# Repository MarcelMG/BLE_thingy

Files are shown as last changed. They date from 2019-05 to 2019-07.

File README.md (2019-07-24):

# BLEthingy
BLEthingy is a small battery-powered device with Bluetooth-Low-Energy connectivity.

The main microcontroller used is an AVR ATtiny3216 from the new tiny-1 series.

BLE connectivity is provided by a RN4871-I RF module.

There is an ADXL345 3-axis accelerometer onboard for motion detection. It sits on a GY-291 breakout-board, which is very cheap and avoids hand-soldering the tiny package of the ADXL345 which is virtually impossible without hot air / reflow oven. The GY-291 has to be slightly modified, see [here](https://github.com/MarcelMG/BLE_thingy/blob/master/hardware/GY-291_mod.md) for further instructions.

A pushbutton and a user LED are also onboard.

On the back of the PCB, a holder for a CR2032 coin cell is mounted.

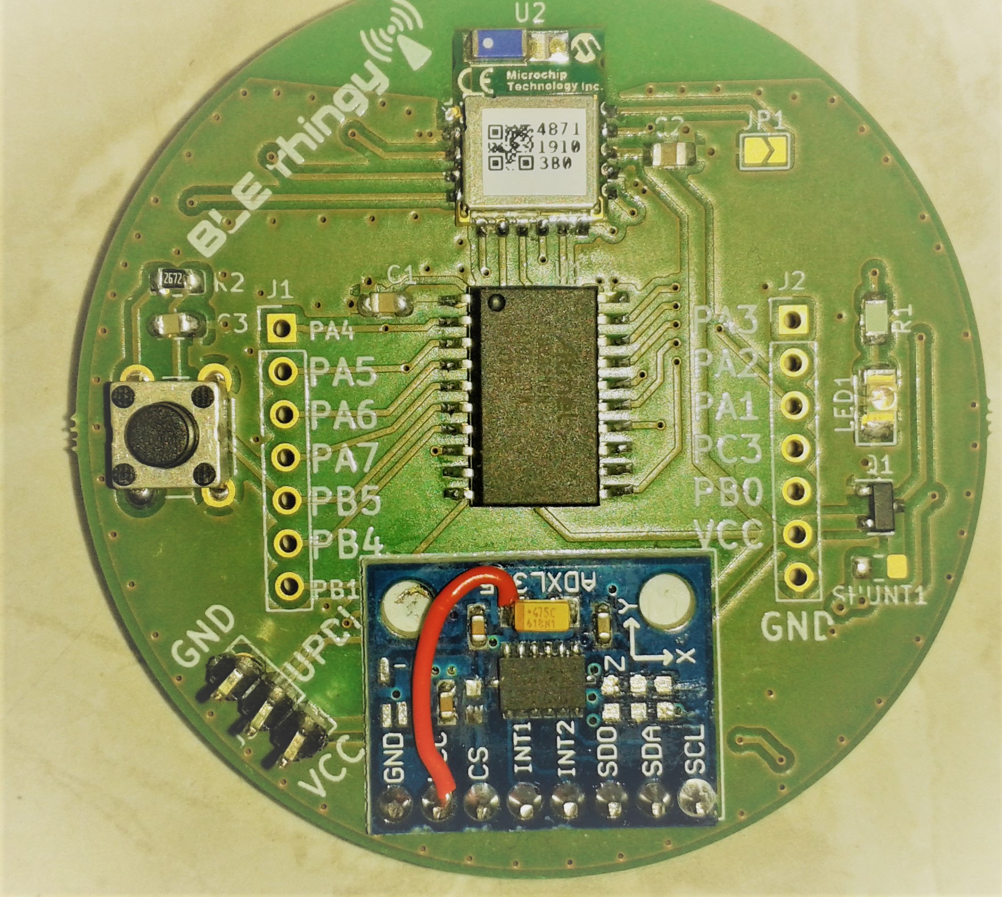
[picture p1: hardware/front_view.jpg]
front_view

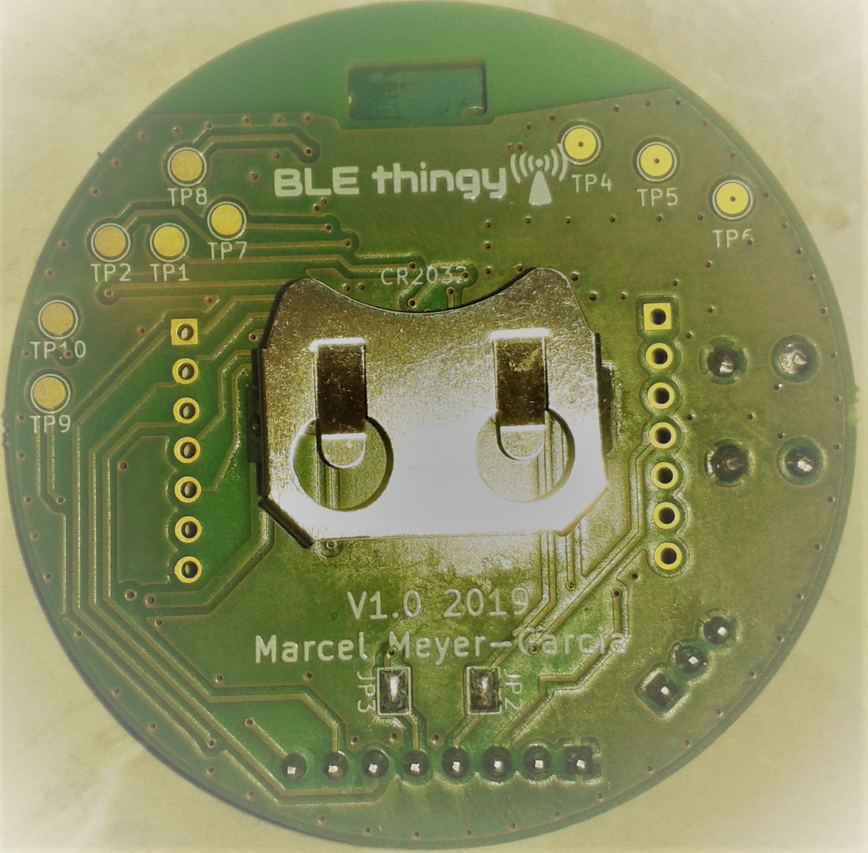
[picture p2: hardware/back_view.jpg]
back_view


An enclosure has been designed which can be 3D-printed.

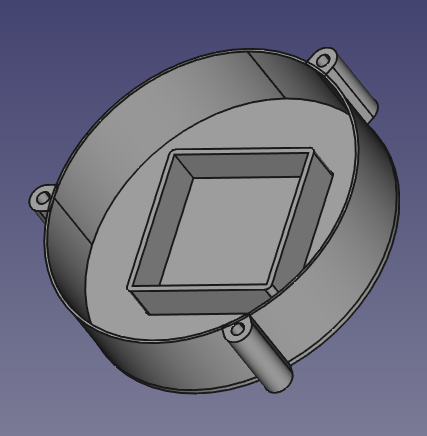
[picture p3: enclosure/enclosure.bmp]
enclosure

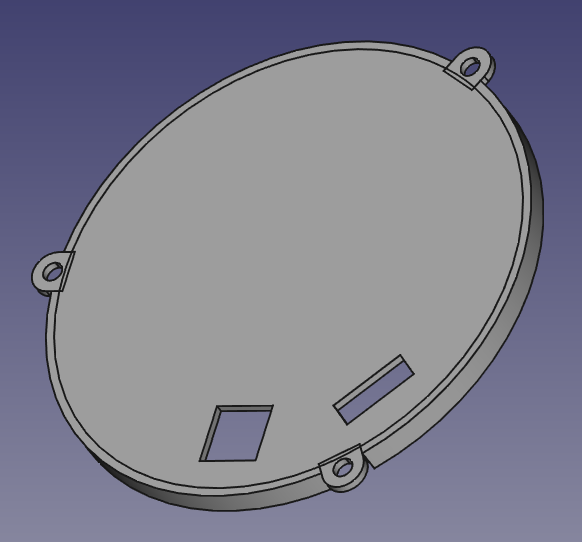
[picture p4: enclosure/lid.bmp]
lid

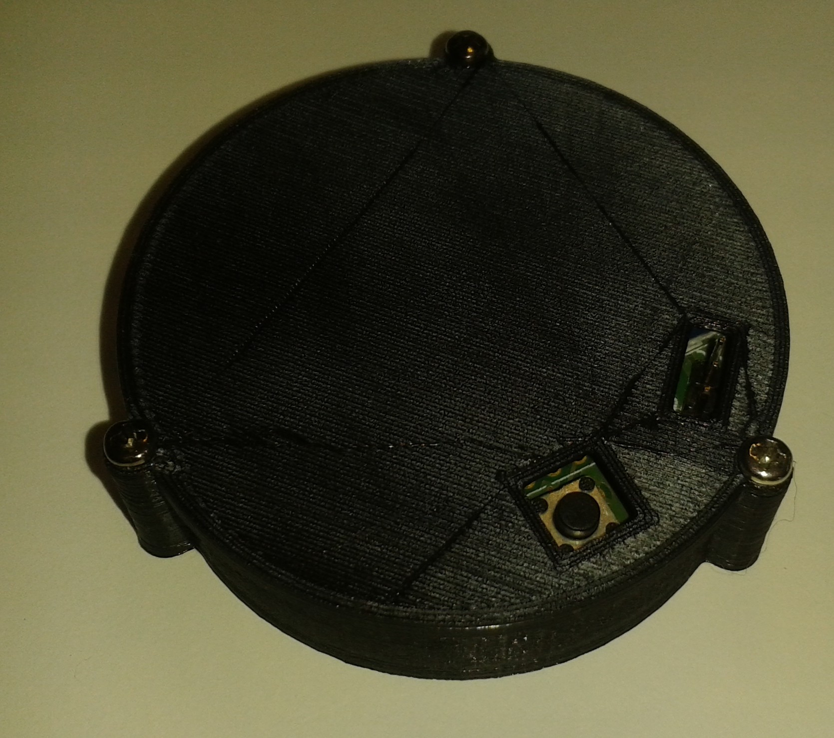
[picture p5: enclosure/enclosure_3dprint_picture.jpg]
enclosure_3dprint_picture


(c) 2019 Marcel Meyer-Garcia
<br />This work (hardware and software) is licensed under a <a rel="license" href="http://creativecommons.org/licenses/by-nc/4.0/">Creative Commons Attribution-NonCommercial 4.0 International License</a>.

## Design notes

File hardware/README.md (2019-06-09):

# PCB files

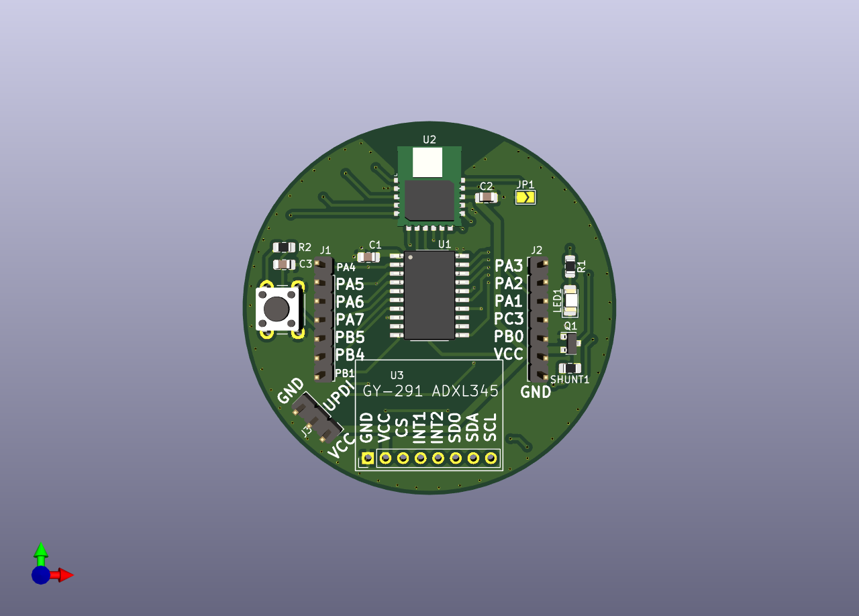
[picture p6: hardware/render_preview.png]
3Drender_front


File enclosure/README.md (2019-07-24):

The enclosure was modeled using [FreeCAD](https://www.freecadweb.org/).
I 3D-printed it with my Ender 3 pro printer

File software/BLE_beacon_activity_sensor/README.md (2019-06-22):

# BLEthingy application

Features:
* BLE Beacon advertisement (non-connectible advertising)
* motion detection with accelerometer
* pushbutton
* temperature measurement
* battery voltage measurement

The advertisement interval is set to 10s, i.e. every 10s an advertisement package is sent via BLE.
The microcontroller is woken up by the RTC every 32s to measure the temperature and the battery voltage and to send those values.
The accelerometer detects activity (motion) and can then wake up the microcontroller to send a message.
The BLE RF-module is also in sleep mode unless woken up by the microcontroller.

The average current consumption is approx. 190µA with the above settings (intervals). During BLE transmission and when the LED is on, the maximum current is about 14mA. The current was measured with the oscilloscope across a 10 Ohm shunt resistor.
This amounts to a battery life of roughly 1 month with the CR2032 coin cell battery.

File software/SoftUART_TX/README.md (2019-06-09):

# SoftUART_TX

a simple software UART transmitter with delays (blocking) to send small messages for debugging and testing purposes.
Output is redirected to *stdout*, so *printf()* can be used for formatted output.
This code is part of the *BLEthingy*-project (uses the AVR ATtiny3216), but can easily be ported to another platform by providing the following:
* *UART_TX_LOW()* - set TX-pin low
* *UART_TX_HIGH()* - set TX-pin high
* *UART_TX_SETOUTPUT()* - configure TX-pin as output
* *_delay_us(x)* - delay for x µs

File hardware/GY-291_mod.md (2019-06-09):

A small breakout board called "GY-291" is used for the ADXL345 accelerometer. It is very cheap and can be found easily. To use it with BLEthingy, it has to be modified as follows:
* desolder the voltage regulator (the small 5-pin device next to the GND label). Since it will be powered by a 3V coin cell, the regulator is not needed and would waste additional current
* desolder all 4 pull-up resistors. Since SPI is used, they are not needed and would waste current. One is located next to the accelerometer in the middle, above the CS label, the other 3 are between the SDO and SDA labels and the coordinate axis label
* solder a small wire between the VCC connector pin and the positive terminal of the yellow tantalum capacitor to bypass the regulator. CAUTION: with tantalum caps, the dark stripe indicates the positive terminal, so it's the opposite of electrolytic caps

The resistors can be easily desoldered using a large tip, as they will stick to the iron's tip. To desolder the regulator, heat the pins on one side and bend it up using a cutter knife while the solder is molten. Then heat the opposite side and remove the component.
I advise to use flux (e.g. from a flux pen) and desoldering wick to clean the pads after desoldering the components. Then clean the flux residues using rubbing alcohol (ethanol).

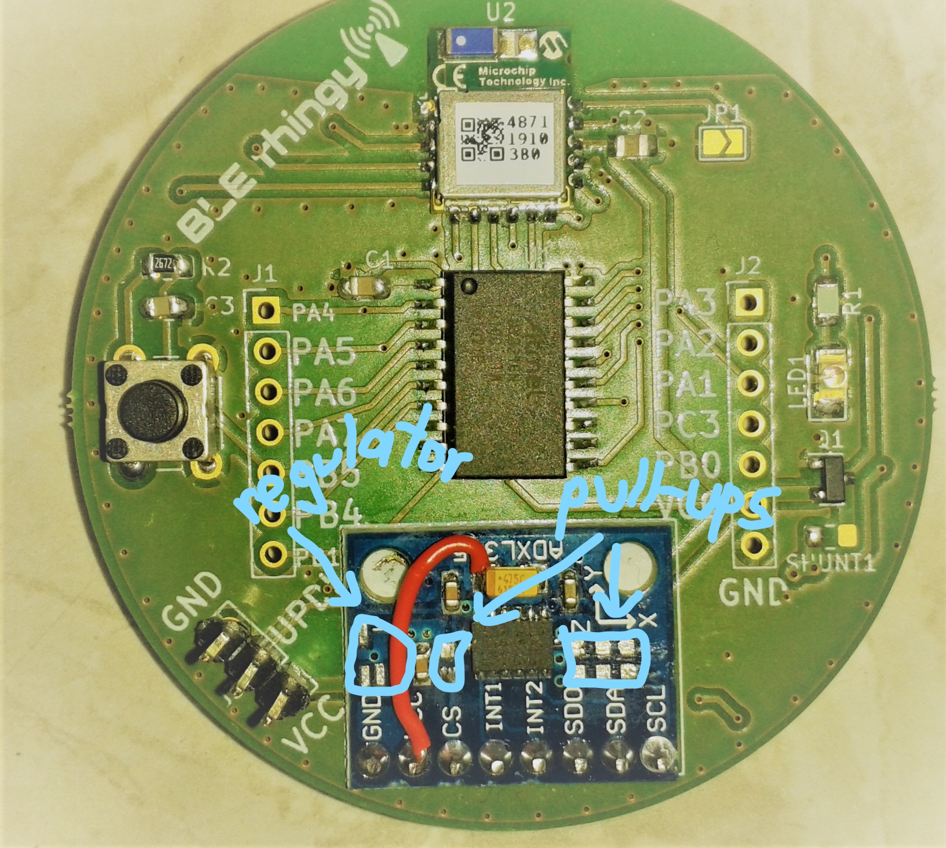
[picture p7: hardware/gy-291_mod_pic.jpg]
mod_pic


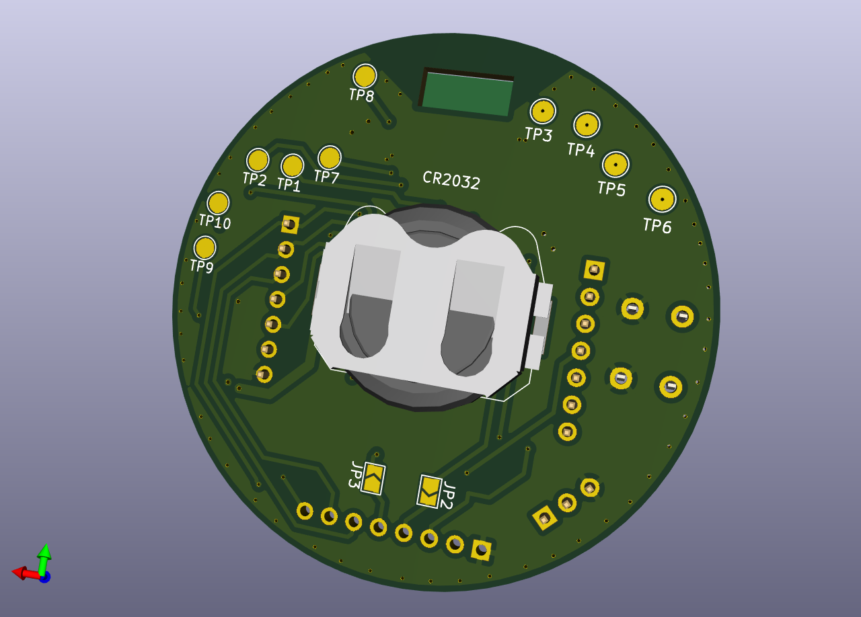
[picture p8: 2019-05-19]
hardware/render_preview_back.png

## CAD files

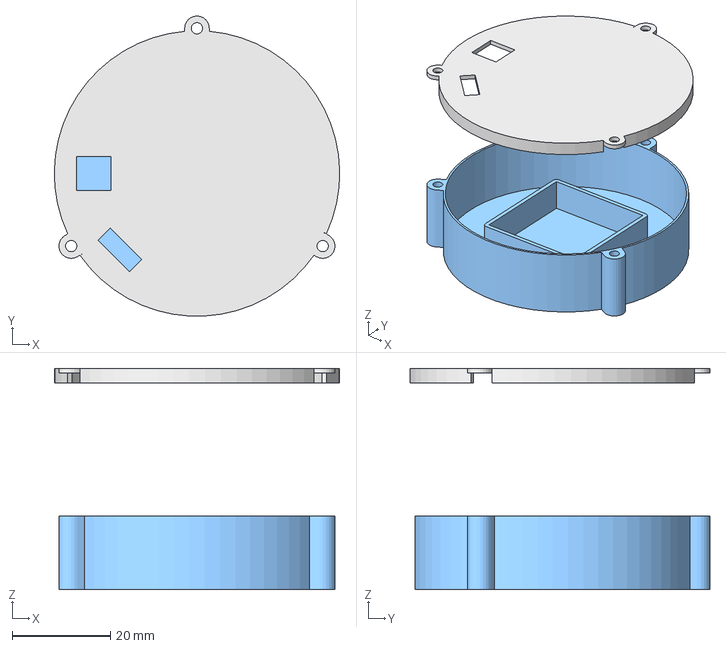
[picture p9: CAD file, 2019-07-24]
enclosure/BLEthingy_enclosure.FCStd
58.0 x 61.0 x 45.0 mm
lower_part (Meshed)
lid (Meshed)

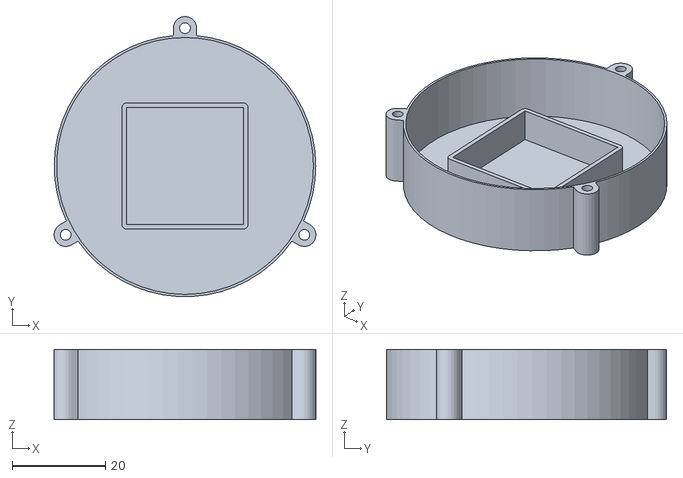
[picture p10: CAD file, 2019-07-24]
enclosure/lower_part.stl
56.1 x 60.0 x 15.0

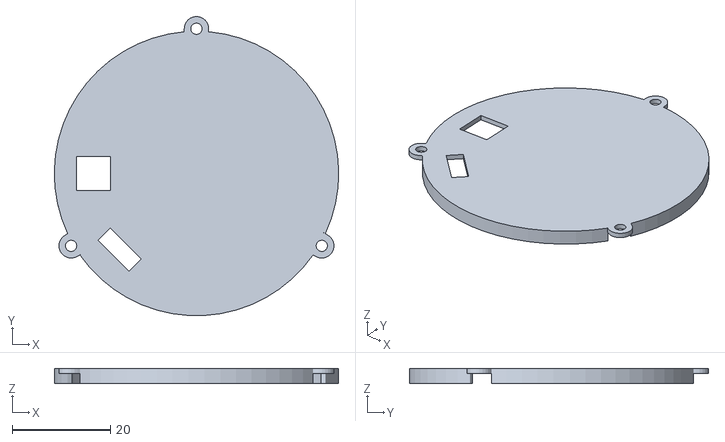
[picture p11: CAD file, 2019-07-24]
enclosure/lid.stl
58.0 x 61.0 x 3.00

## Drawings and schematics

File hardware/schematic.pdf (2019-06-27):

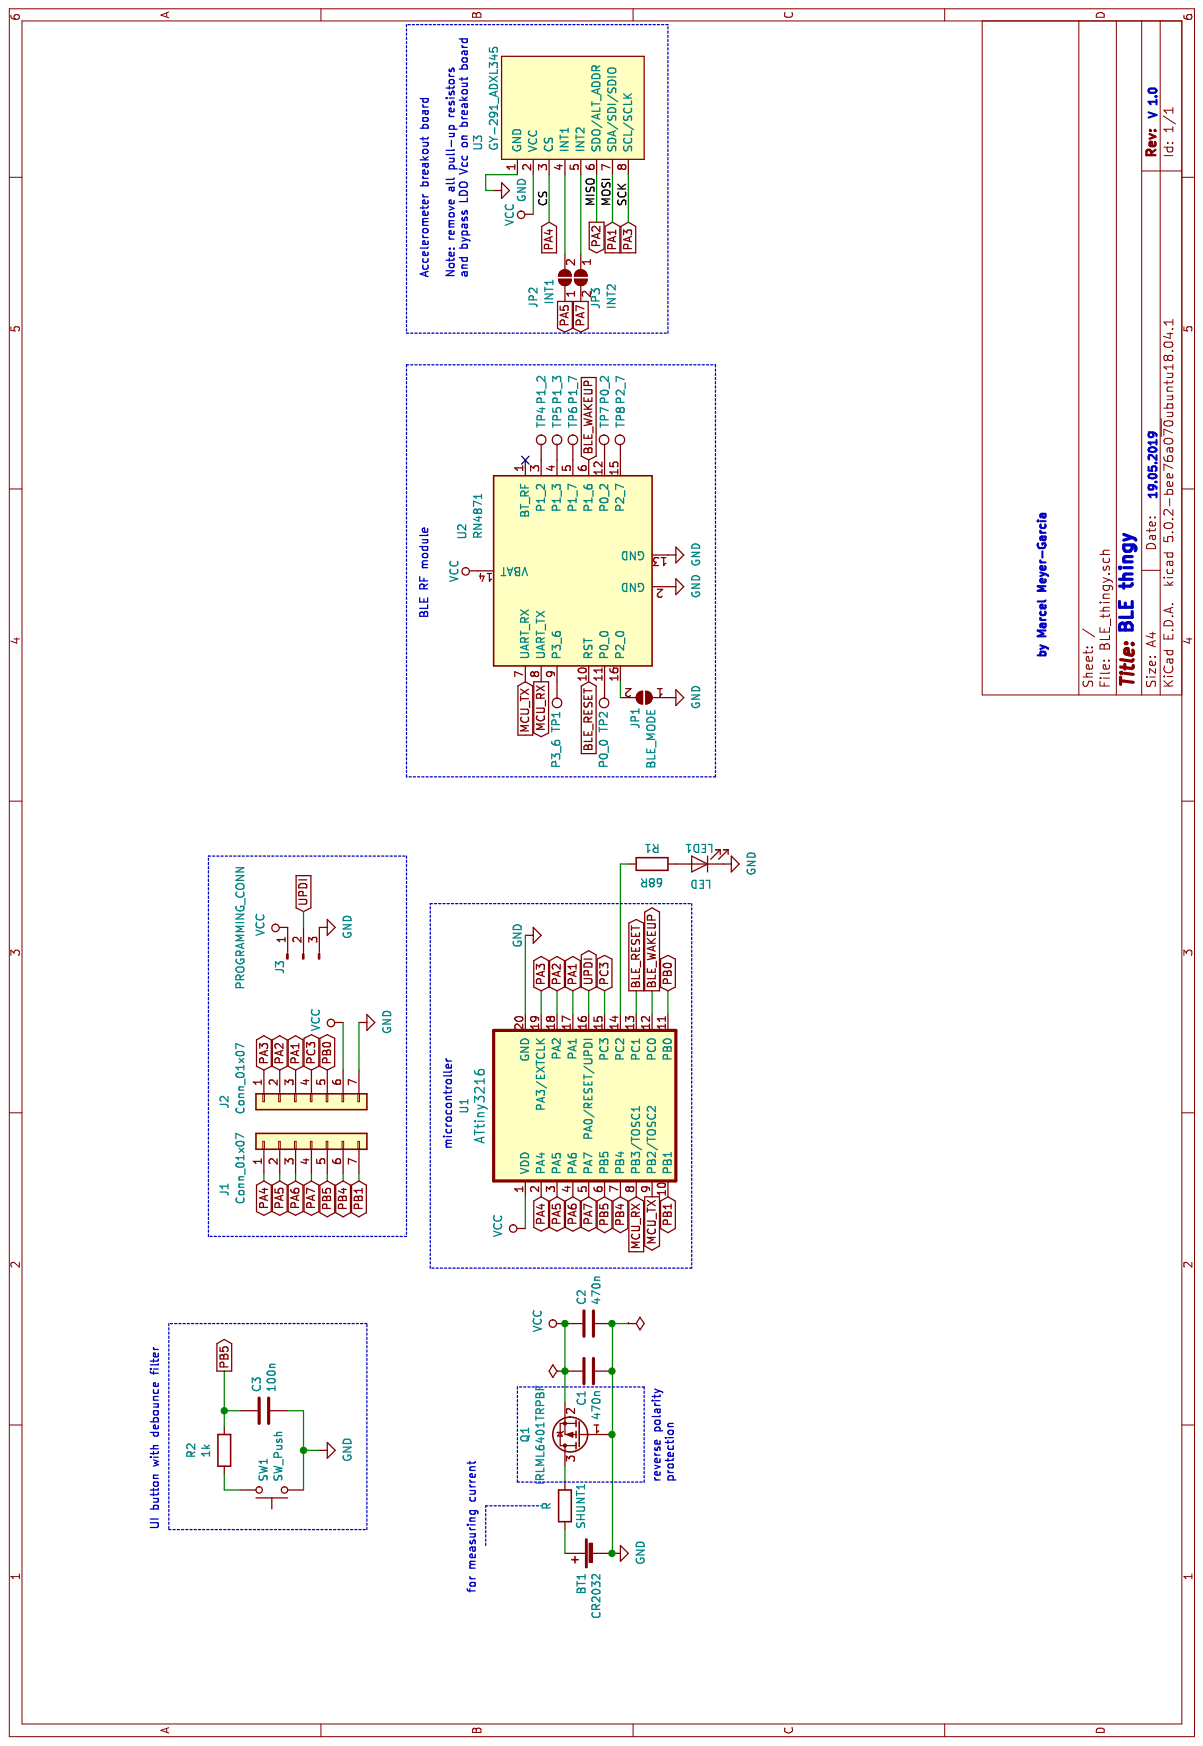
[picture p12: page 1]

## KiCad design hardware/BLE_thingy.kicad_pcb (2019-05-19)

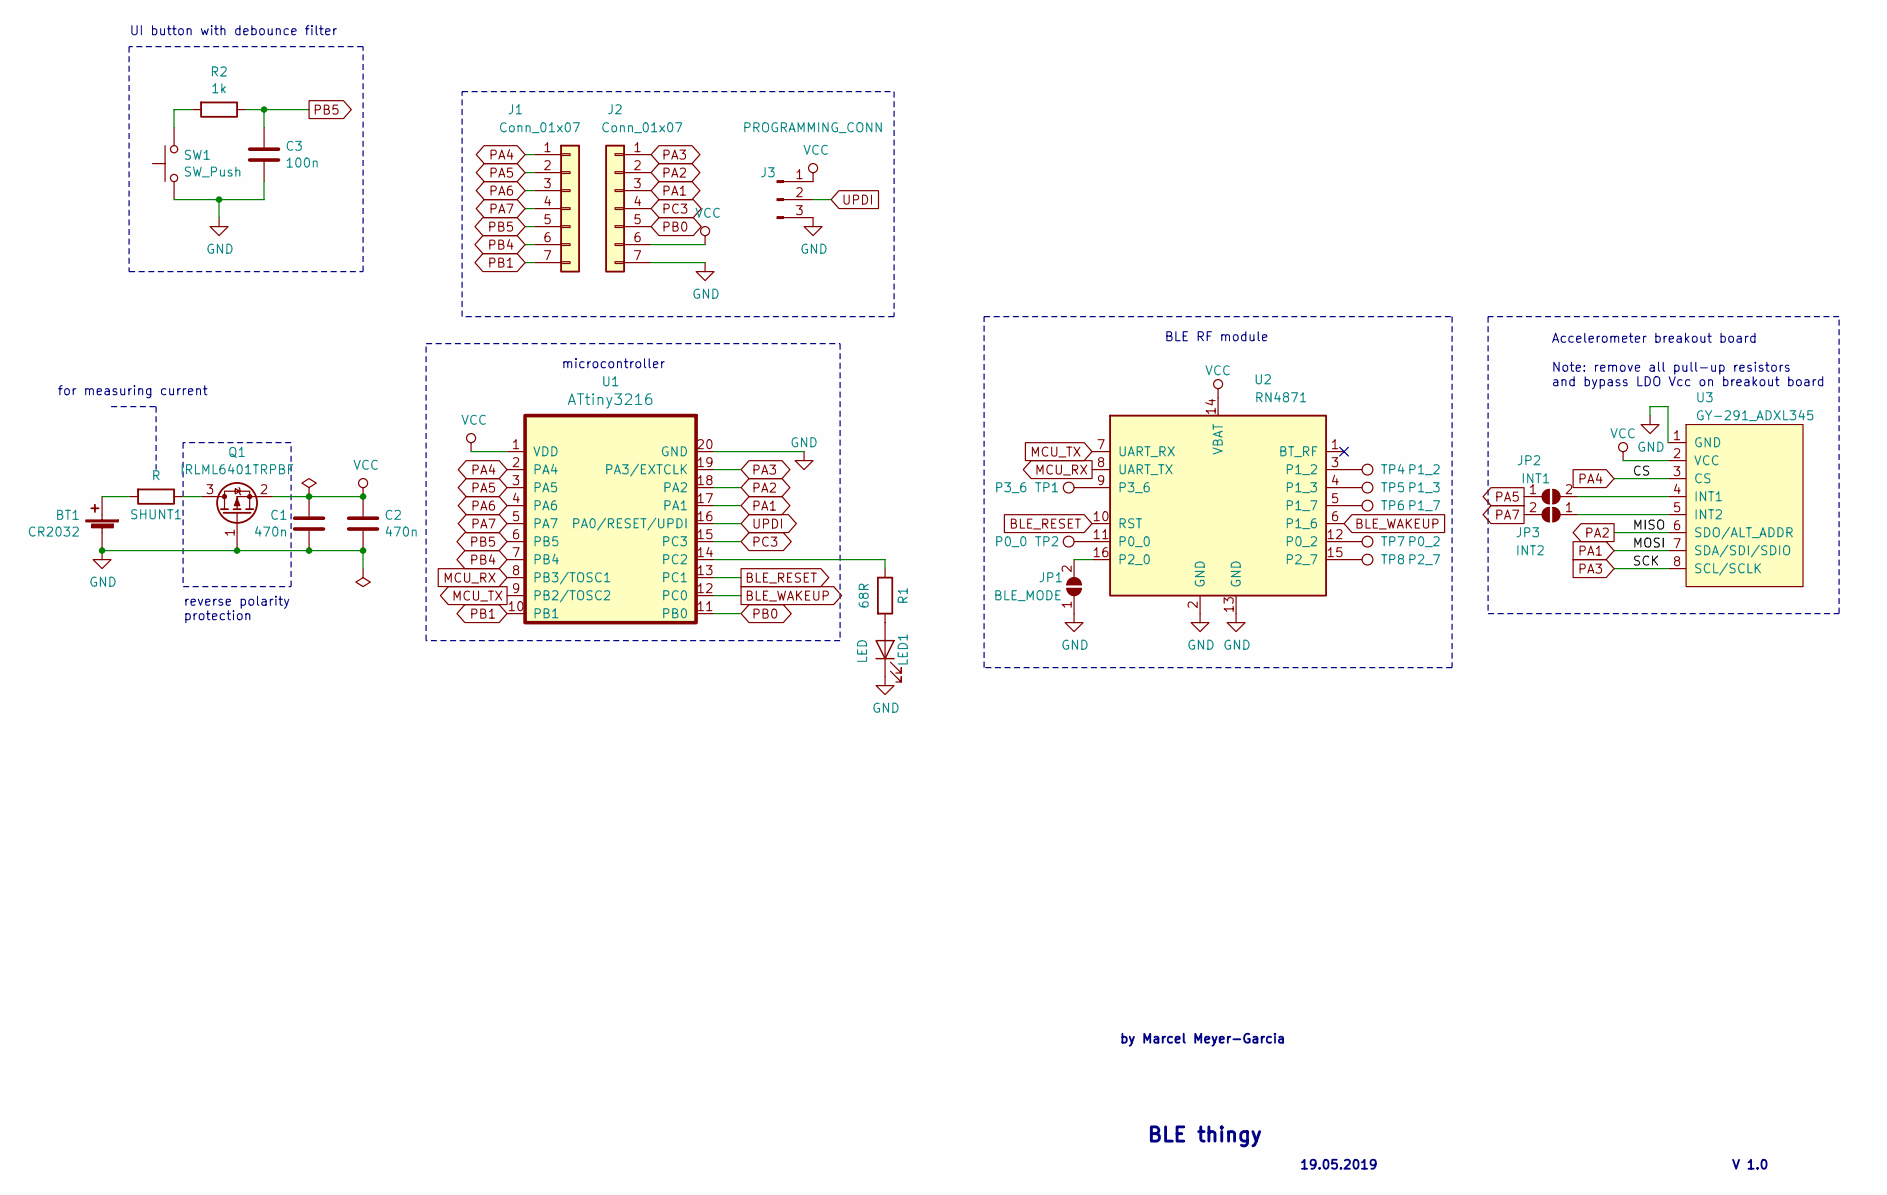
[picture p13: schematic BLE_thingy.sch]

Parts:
BT1: CR2032; BatteryHolder_Keystone_3034_1x20mm
C1, C2: 470n; C_0805_2012Metric_Pad1.15x1.40mm_HandSolder
C3: 100n; C_0805_2012Metric_Pad1.15x1.40mm_HandSolder
J1, J2: Conn_01x07; PinHeader_1x07_P2.54mm_Vertical
J3: PROGRAMMING_CONN; PinHeader_1x03_P2.54mm_Vertical
JP1: BLE_MODE; SolderJumper-2_P1.3mm_Open_TrianglePad1.0x1.5mm
JP2: INT1; SolderJumper-2_P1.3mm_Open_TrianglePad1.0x1.5mm
JP3: INT2; SolderJumper-2_P1.3mm_Open_TrianglePad1.0x1.5mm
LED1: LED; LED_1206_3216Metric_Pad1.42x1.75mm_HandSolder
Q1: IRLML6401TRPBF; SOT-23
R1: 68R; R_0805_2012Metric_Pad1.15x1.40mm_HandSolder
R2: 1k; R_0805_2012Metric_Pad1.15x1.40mm_HandSolder
SHUNT1: R; R_0805_2012Metric_Pad1.15x1.40mm_HandSolder
SW1: SW_Push; SW_PUSH_6mm_H4.3mm
TP1: P3_6; TestPoint_Pad_D2.0mm
TP2: P0_0; TestPoint_Pad_D2.0mm
TP4: P1_3; TestPoint_Pad_D2.0mm
TP5: P1_2; TestPoint_Pad_D2.0mm
TP6: P1_7; TestPoint_Pad_D2.0mm
TP7: P0_2; TestPoint_Pad_D2.0mm
TP8: P2_7; TestPoint_Pad_D2.0mm
U1: ATtiny3216; SOIC-20_elongated_pads
U2: RN4871; Microchip_RN4871
U3: GY-291_ADXL345; GY-291_ADXL345_breakout_board

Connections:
BLE_RESET: U1.13 (PC1), U2.10 (RST)
BLE_WAKEUP: U1.12 (PC0), U2.6 (P1_6)
GND: BT1.2 (-), C1.2, C2.2, C3.2, J2.7, J3.3, JP1.1 (A), LED1.1 (K), Q1.1 (G), SW1.1, U1.20 (GND), U2.2 (GND), U2.13 (GND), U3.1 (GND)
MCU_RX: U1.8 (PB3/TOSC1), U2.8 (UART_TX)
MCU_TX: U1.9 (PB2/TOSC2), U2.7 (UART_RX)
unnamed 5: BT1.1 (+), SHUNT1.2; also elsewhere on the board
unnamed: JP1.2 (B), U2.16 (P2_0)
unnamed: JP2.2 (B), U3.4 (INT1)
unnamed: JP3.1 (A), U3.5 (INT2)
unnamed: LED1.2 (A), R1.2
unnamed 10: Q1.3 (D), SHUNT1.1; also elsewhere on the board
unnamed: R1.1, U1.14 (PC2)
unnamed: R2.2, SW1.2
unnamed: TP1.1, U2.9 (P3_6)
unnamed: TP2.1, U2.11 (P0_0)
unnamed: TP4.1, U2.3 (P1_2)
unnamed: TP5.1, U2.4 (P1_3)
unnamed: TP6.1, U2.5 (P1_7)
unnamed: TP7.1, U2.12 (P0_2)
unnamed: TP8.1, U2.15 (P2_7)
PA1: J2.3, U1.17 (PA1), U3.7 (SDA/SDI/SDIO)
PA2: J2.2, U1.18 (PA2), U3.6 (SDO/ALT_ADDR)
PA3: J2.1, U1.19 (PA3/EXTCLK), U3.8 (SCL/SCLK)
PA4: J1.1, U1.2 (PA4), U3.3 (CS)
PA5: J1.2, JP2.1 (A), U1.3 (PA5)
PA6: J1.3, U1.4 (PA6)
PA7: J1.4, JP3.2 (B), U1.5 (PA7)
PB0: J2.5, U1.11 (PB0)
PB1: J1.7, U1.10 (PB1)
PB4: J1.6, U1.7 (PB4)
PB5: C3.1, J1.5, R2.1, U1.6 (PB5)
PC3: J2.4, U1.15 (PC3)
UPDI: J3.2, U1.16 (PA0/RESET/UPDI)
VCC: C1.1, C2.1, J2.6, J3.1, Q1.2 (S), U1.1 (VDD), U2.14 (VBAT), U3.2 (VCC)

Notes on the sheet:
Accelerometer breakout board Note: remove all pull-up resistors and bypass LDO Vcc on breakout board
for measuring current
BLE RF module
microcontroller
reverse polarity protection
UI button with debounce filter
BLE thingy
19.05.2019
V 1.0
by Marcel Meyer-Garcia

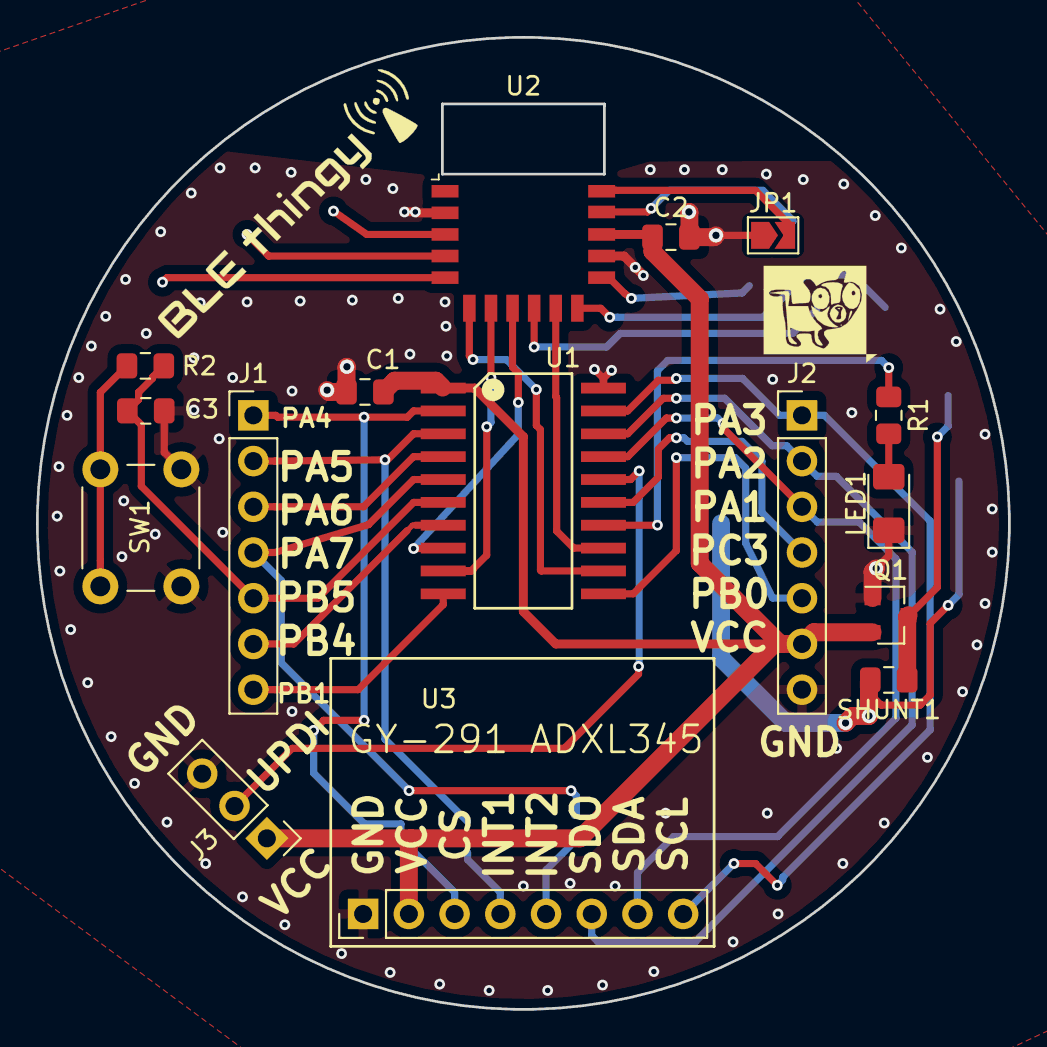
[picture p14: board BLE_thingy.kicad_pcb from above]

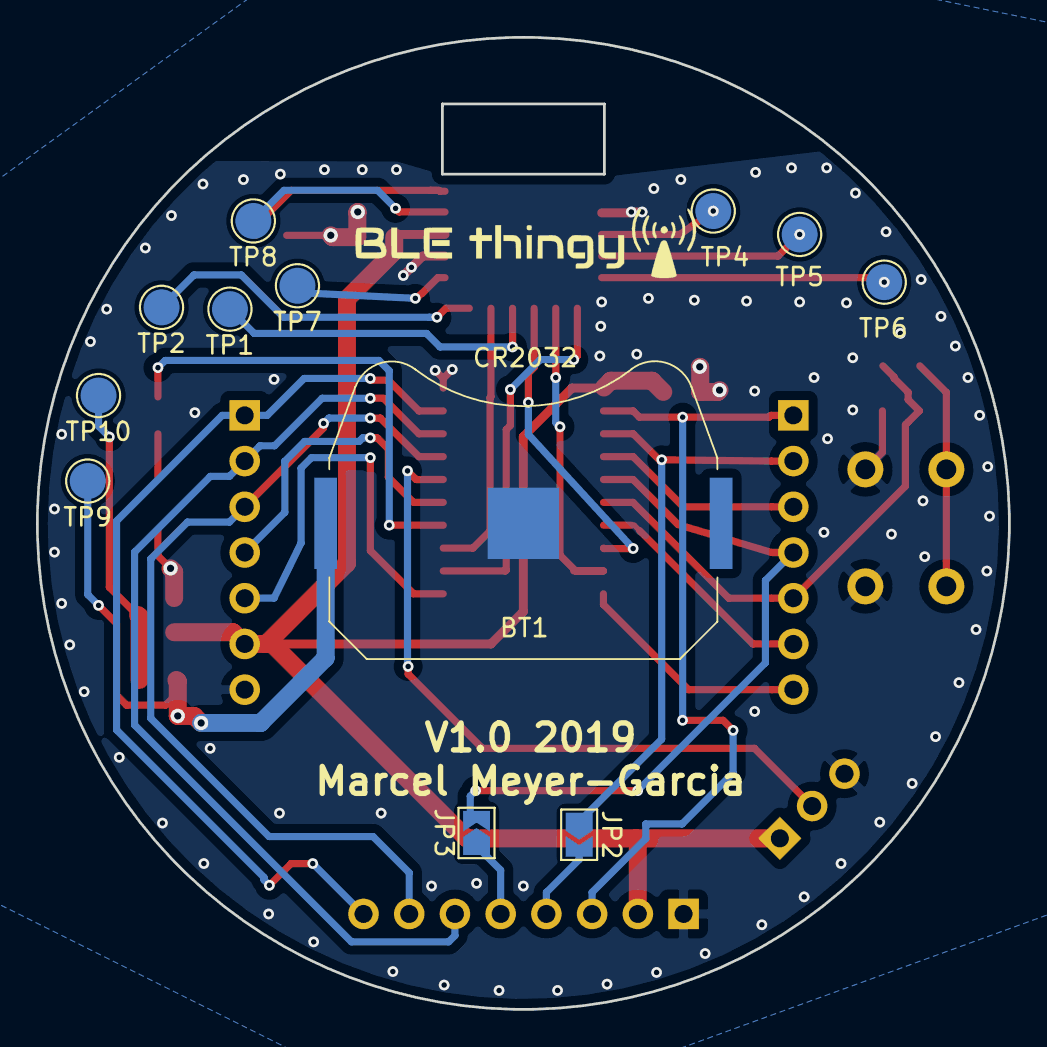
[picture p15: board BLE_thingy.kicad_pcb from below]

Board: 2 copper layers, 54.0 x 54.0 mm, 28 parts (12 on the bottom side), 34 nets.

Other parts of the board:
TP9: SHUNT+; TestPoint_Pad_D2.0mm
TP10: SHUNT-; TestPoint_Pad_D2.0mm

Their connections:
unnamed 5: TP9.1; also elsewhere on the board
unnamed 10: TP10.1; also elsewhere on the board

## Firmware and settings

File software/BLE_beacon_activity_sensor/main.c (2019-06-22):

/*	BLEthingy -- Accelerometer Activity Detection + Temperature & Voltage Measurement BLE Beacon */

#include <avr/io.h>
#include <avr/interrupt.h>
#include <avr/sleep.h>
#include "RN4871.h"
#include "ADXL345.h"

// interrupt variables
volatile bool activity = false;
volatile bool rtc_wakeup = false;
volatile bool pushbutton_pressed = false;
volatile uint8_t err = 0;

// pushbutton interrupt handler, wakes CPU from power-down sleep mode
ISR(PORTB_PORT_vect){
	if(PORTB.INTFLAGS != PIN5_bm){
		err = 3; // error: wrong pin has triggered the interrupt
	}else if( !(PORTB.IN & PIN5_bm) ){ // a falling edge has triggered the interrupt (button has been pressed)
			pushbutton_pressed = true;
	} // else a rising edge has triggered the interrupt (releasing the button) and we do nothing

	PORTB.INTFLAGS = PIN5_bm; // clear interrupt flag
}


// ADXL345 interrupt handler, wakes CPU from power-down sleep mode
ISR(PORTA_PORT_vect){
	if(PORTA.INTFLAGS != PIN5_bm){
		err = 1; // error: wrong pin has triggered the interrupt
	}
	if(!ADXL345_checkInterrupt(ADXL345_activityInterrupt)){ // ADXL345_checkInterrupt() has to be called within the ISR to clear the interrupt flag on the ADXL345
		err = 2;// error: wrong event on the ADXL345 has triggered the interrupt
	}
	activity = true; // the activity interrupt has been triggered
	PORTA.INTFLAGS = PIN5_bm; // clear interrupt flag
}

// RTC PIT interrupt handler, wakes CPU from power-down sleep mode. Occurs every 4s
ISR(RTC_PIT_vect){
	rtc_wakeup = true;
	RTC.PITINTFLAGS = RTC_PI_bm;	// clear interrupt flag
}

// measure internal temperature of ATtiny2316 in °C
int16_t measure_internal_temperature(){
	// setup ADC to measure temperature
	VREF.CTRLA = VREF_ADC0REFSEL_1V1_gc;
	ADC0.CTRLC = ADC_PRESC_DIV256_gc | ADC_REFSEL_INTREF_gc | ADC_SAMPCAP_bm;
	ADC0.MUXPOS = ADC_MUXPOS_TEMPSENSE_gc;
	ADC0.CTRLA = ADC_ENABLE_bm;
	ADC0.COMMAND = ADC_STCONV_bm;
	while( !(ADC0.INTFLAGS & ADC_RESRDY_bm) );
	// calculate T in °C
	int8_t sigrow_offset = SIGROW.TEMPSENSE1;
	uint8_t sigrow_gain = SIGROW.TEMPSENSE0;
	int32_t tmp = ADC0.RES - sigrow_offset;
	tmp *= sigrow_gain;
	tmp += 0x80;
	tmp >>= 8;
	tmp -= 273; // °K to °C
	ADC0.CTRLA = 0; // disable ADC
	return ((int16_t) tmp);	
}

// measure VCC voltage internally, result in mV
uint16_t measure_VCC(){
	// setup ADC to measure VCC
	ADC0.MUXPOS = ADC_MUXPOS_INTREF_gc;
	ADC0.CTRLC = ADC_PRESC_DIV256_gc | ADC_REFSEL_VDDREF_gc;
	ADC0.CTRLA = ADC_ENABLE_bm;
	ADC0.COMMAND = ADC_STCONV_bm;
	while( !(ADC0.INTFLAGS & ADC_RESRDY_bm) );
	ADC0.CTRLA = 0; // disable ADC
	return (1126400 / ADC0.RES); // VCC in mV	
}

int main(void)
{
	/* ONBOARD LED SETUP */
	PORTC.DIRSET = PIN2_bm;	// pin PC2 (LED) as output
	PORTC.OUTCLR = PIN2_bm; // LED off
	
	/* ONBOARD PUSHBUTTON SETUP */
	PORTB.DIRCLR = PIN5_bm; // config pin PB5 as input
	PORTB.PIN5CTRL = PORT_PULLUPEN_bm | PORT_ISC_BOTHEDGES_gc; // enable pull-up and interrupt on both edges (NOTE: only LEVEL and BOTHEDGES can wake the µC from sleep, so we can't use falling edge)
	
	/* BLE BEACON SETUP */
	RN4871_init();
	RN4871_setup_beacon(6400); // setup Beacon with 10s advertisement interval
	
	/* ACCELEROMETER SETUP */
	ADXL345_init();
	PORTA.DIRCLR = PIN5_bm; // config pin PA5 (connected to ADXL345 INT1) as input
	PORTA.PIN5CTRL = PORT_ISC_LEVEL_gc; // enable LEVEL interrupt (triggers when input is low) NOTE: only LEVEL and BOTHEDGES can wake the µC from sleep!
	ADXL345_configActivityDetection(5.0, false, ADXL345_actXY); // setup activity detection in dc-coupled mode, with X- and Y-axis and a threshold of 5.0 m/s²
	ADXL345_mapInterrupt_1(ADXL345_activityInterrupt); // map the activity interrupt to the INT1 pin of the ADXL345
	ADXL345_setInterrupt(ADXL345_watermarkInterrupt, false); // disable watermark interrupt, as it is enabled by default
	ADXL345_setInterruptPolarity(ActiveLow); // set interrupt polarity to active low (affects all interrupts)
	ADXL345_setInterrupt(ADXL345_activityInterrupt, true); // enable activity interrupt, it works even within sleep mode
	ADXL345_enterSleepMode(ADXL345_sleepMode_8Hz); // enter sleep mode and set the sample rate in sleep mode to 8Hz
	
	/* REDUCE POWER CONSUMPTION OF GPIOs */
	// set unused pins as inputs with pull-up and disable input buffer to reduce power consumption
	PORTA.DIRCLR = PIN6_bm;
	PORTA.PIN6CTRL = PORT_PULLUPEN_bm | PORT_ISC_INPUT_DISABLE_gc;
	PORTB.DIRCLR = PIN0_bm | PIN1_bm | PIN4_bm;
	PORTB.PIN0CTRL = PORT_PULLUPEN_bm | PORT_ISC_INPUT_DISABLE_gc;
	PORTB.PIN1CTRL = PORT_PULLUPEN_bm | PORT_ISC_INPUT_DISABLE_gc;
	PORTB.PIN4CTRL = PORT_PULLUPEN_bm | PORT_ISC_INPUT_DISABLE_gc;
	PORTC.DIRCLR = PIN3_bm;
	PORTC.PIN3CTRL = PORT_PULLUPEN_bm | PORT_ISC_INPUT_DISABLE_gc;
	BOD.CTRLA &=~(BOD_SLEEP0_bm | BOD_SLEEP1_bm); // disable brown-out-detector in sleep mode to reduce power consumption
	
	/* RTC SETUP */
	while(RTC.STATUS); // wait until RTC is synchronized
	RTC.CLKSEL = RTC_CLKSEL_INT1K_gc; // select 1024 Hz clock from internal 32kHz oscillator
	RTC.PITINTCTRL = RTC_PI_bm; // enable periodic interrupt
	RTC.PITCTRLA = RTC_PERIOD_CYC32768_gc | RTC_PITEN_bm;	// select interrupt period and enable PIT
		
	/* SLEEP MODE SETUP */	
	sei(); // globally enable interrupts on the µC
	set_sleep_mode(SLEEP_MODE_PWR_DOWN); // set sleep mode to power-down
	sleep_enable();	// enable sleep mode
	
	/* VARIABLES FOR BLE BEACON ADVERTISEMENT PACKET */
	uint16_t major, minor;
	const uint8_t txpwr = 100;
	
	/* MAIN LOOP */
	while (1){
		sleep_cpu(); // put ATtiny3216 in sleep mode (again)
		/* if either the RTC, the pushbutton or the accelerometer interrupt wake up the CPU, we continue here */
		if(pushbutton_pressed){
			major = 0xEEEE;
			minor = 0xEEEE;
			pushbutton_pressed = false;
		}else if(activity){ // accelerometer interrupt has caused wakeup
			major = 0xFFFF;
			minor = 0xFFFF;
			activity = false;
		}else{ // RTC interrupt has caused wakeup
			major = measure_internal_temperature();
			minor = measure_VCC();
			rtc_wakeup = false;
		}
		PORTC.OUTSET = PIN2_bm; // LED on
		RN4871_wakeup();
		PORTC.OUTCLR = PIN2_bm; // LED off
		iBeacon_advertise(minor, major, txpwr); // advertise as Beacon
		RN4871_sleep();
	}
	return 0;
}

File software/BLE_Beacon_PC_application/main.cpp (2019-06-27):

#include <iostream>
#include <string>
using namespace std;

int main()
{
    string strbuf, tmpstr, minor_str, major_str, txpwr_str;
    const string UUID = "123456789ABCDEF123456789ABCDEF12";
    unsigned int minor, major, txpwr;

    while(1){
        strbuf = "";
        size_t pos = string::npos;
        while(pos == string::npos){
            cin >> tmpstr;
            strbuf += tmpstr;
            pos = strbuf.find(">");
        }
        pos = strbuf.find(UUID);
        if(pos != string::npos){
            printf("\033c"); // clear console
            pos += UUID.size();
            minor_str = strbuf.substr(pos, 4);
            minor = stoul(minor_str, nullptr, 16);
            pos += 4;
            major_str = strbuf.substr(pos, 4);
            major = stoul(major_str, nullptr, 16);
            pos += 6;
            txpwr_str = strbuf.substr(pos, 2);
            txpwr = stoul(txpwr_str, nullptr, 16);
            if( major==0xFFFF && minor==0xFFFF ){
               cout<<"MOTION DETECTED!"<<endl;
            }else if( major==0xEEEE && minor==0xEEEE ){
               cout<<"BUTTON PRESSED!"<<endl;
            }else{
               cout<<"battery voltage: "<<(0.001*minor)<<"V\t\ttemperature: "<<(int16_t)major<<"°C\t\tttx_power= "<<txpwr<<endl;
            }

        }
    }

    return 0;
}

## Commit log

2019-06-22 changed RTC wakeup interval and BLE Adv. interval, +LED flash
2019-06-27 updated schematic
2019-07-24 initial upload
    [BLEthingy_enclosure.FCStd, lid.stl, lower_part.stl]
